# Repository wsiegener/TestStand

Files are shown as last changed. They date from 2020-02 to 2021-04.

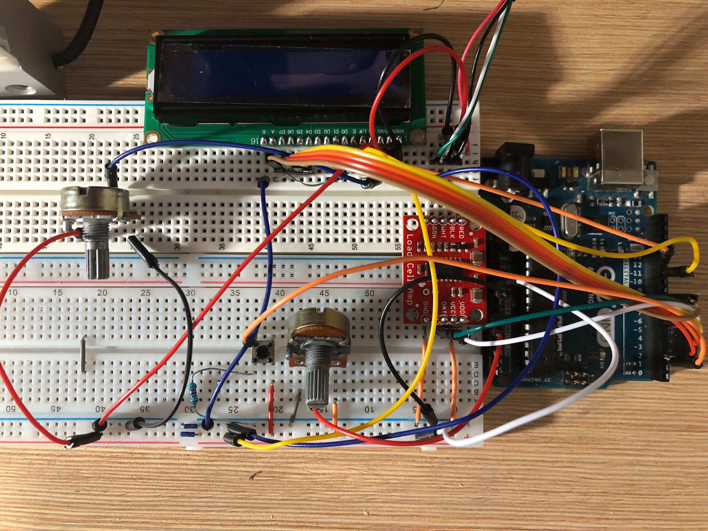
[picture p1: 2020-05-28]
Documentation/Breadboard_pic2_2_26.jpg

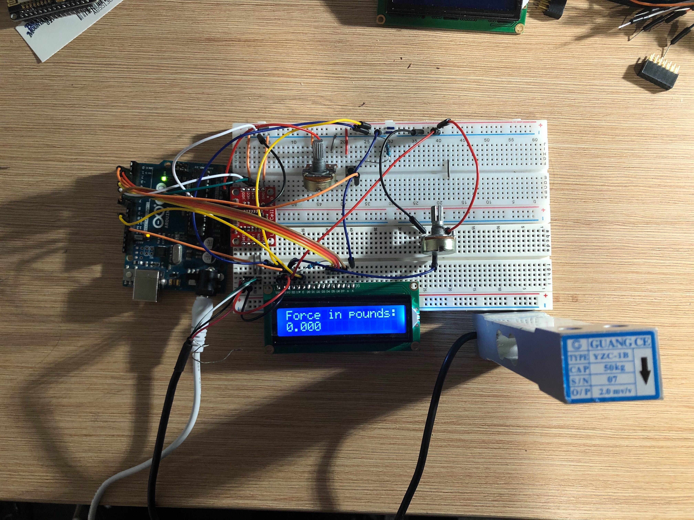
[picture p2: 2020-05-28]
Documentation/Breadboard_pic1_2_26.jpg

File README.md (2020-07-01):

# Model Rocket Thrust Measurement Test Stand
* An RIT SPEX solo project developed by Billy Siegener

### Current Functionality
* Records and displays measurements from a 50kg load cell via an [HX711](https://cdn.sparkfun.com/datasheets/Sensors/ForceFlex/hx711_english.pdf "Amplifier datasheet") load cell amplifier module.
  * [HX711 Library](https://github.com/bogde/HX711 "HX711Library")
* Automatic scale factor tuning
* Improved tare functionality for dealing with noisy circuitry
* 1602A LCD implemenation

### Future Functionality
* ...

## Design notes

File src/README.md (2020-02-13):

# Model Rocket Thrust Measurement Test Stand
* An RIT SPEX solo project developed by Billy Siegener

### Current Functionality
* Records and displays measurements from a 50kg load cell via an [HX711](https://cdn.sparkfun.com/datasheets/Sensors/ForceFlex/hx711_english.pdf "Amplifier datasheet") load cell amplifier module.
  * [HX711 Library](https://github.com/bogde/HX711 "HX711Library")
* Scale factor tuning via potentiometer
* Improved tare functionality for dealing with noisy circuitry

### Future Functionality
* Wireless data transmission via [NRF24L01+](https://www.sparkfun.com/datasheets/Components/nRF24L01_prelim_prod_spec_1_2.pdf "Datasheet") modules.
  * [NRF24L01 Library](https://github.com/nRF24/RF24)
* 1602A LCD implemenation
* ...

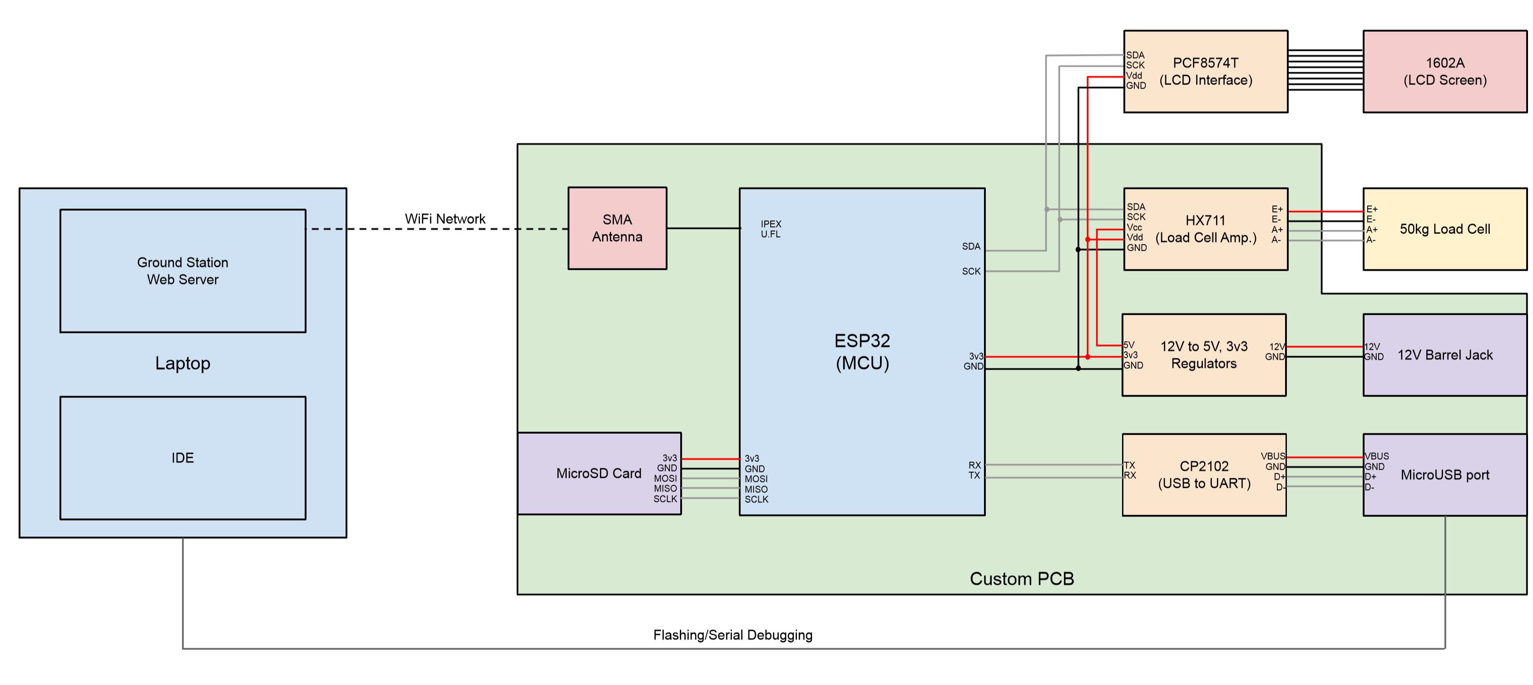
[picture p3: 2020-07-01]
Documentation/BlockDiagram_v1c.JPG

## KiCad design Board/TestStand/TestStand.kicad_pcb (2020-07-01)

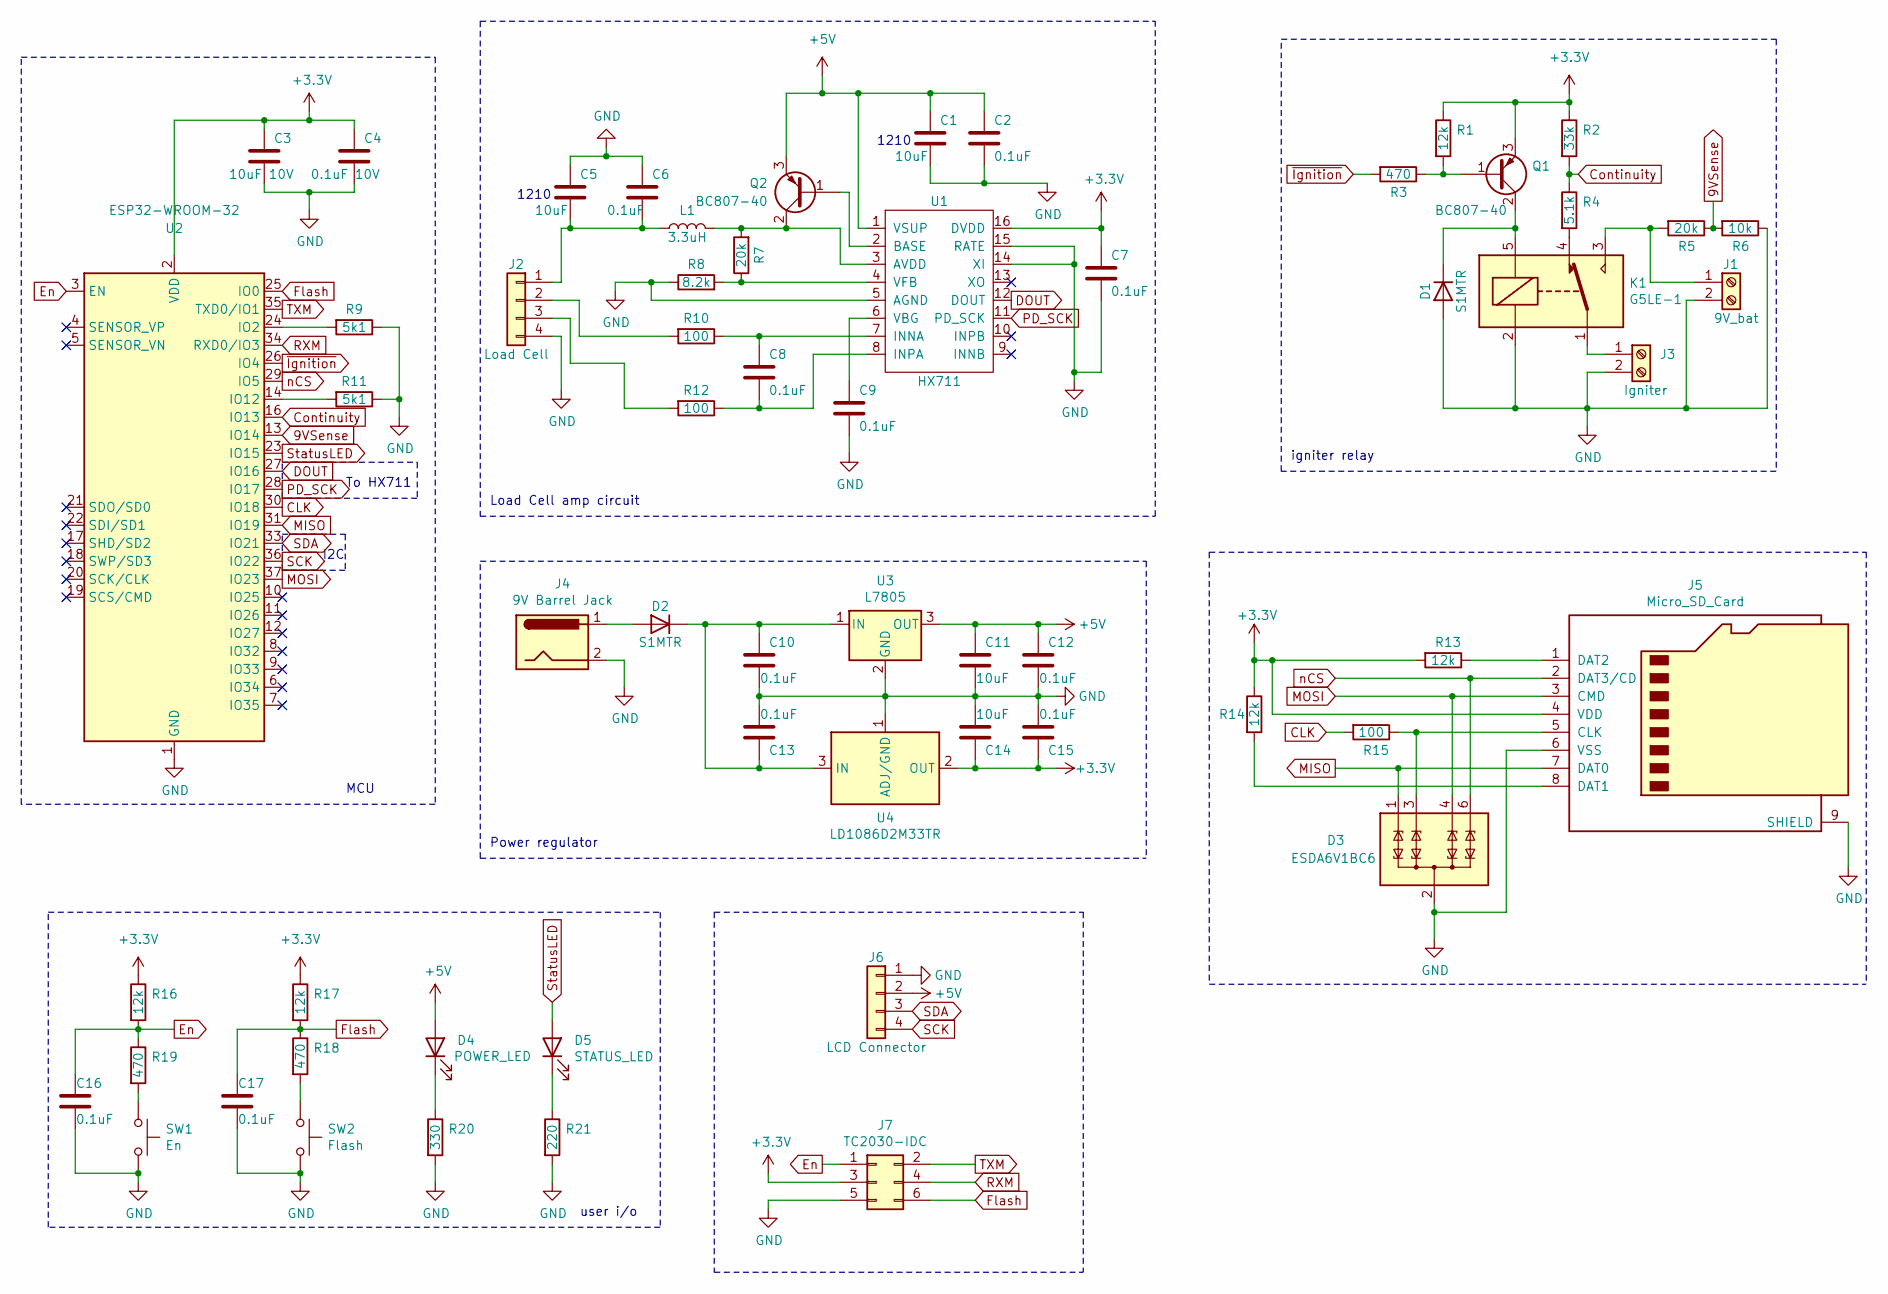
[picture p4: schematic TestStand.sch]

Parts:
C1, C5: 10uF; C_1210_3225Metric_Pad1.42x2.65mm_HandSolder
C2, C6, C7, C8, C9, C10, C12, C13, C15, C16, C17: 0.1uF; C_0805_2012Metric_Pad1.15x1.40mm_HandSolder
C3: 10uF 10V; C_0805_2012Metric_Pad1.15x1.40mm_HandSolder
C4: 0.1uF 10V; C_0805_2012Metric_Pad1.15x1.40mm_HandSolder
C11, C14: 10uF; C_0805_2012Metric_Pad1.15x1.40mm_HandSolder
D1, D2: S1MTR; D_SMA_Handsoldering
D3: ESDA6V1BC6; SOT-23-6
D4: POWER_LED; LED_Rectangular_W5.0mm_H2.0mm
D5: STATUS_LED; LED_Rectangular_W5.0mm_H2.0mm
J1: 9V_bat; TerminalBlock_Phoenix_PT-1,5-2-5.0-H_1x02_P5.00mm_Horizontal
J2: Load Cell; Molex_Micro-Fit_3.0_43045-0400_2x02_P3.00mm_Horizontal
J3: Igniter; TerminalBlock_Phoenix_PT-1,5-2-5.0-H_1x02_P5.00mm_Horizontal
J4: 9V Barrel Jack; BarrelJack_CUI_PJ-036AH-SMT_Horizontal
J5: Micro_SD_Card; microSD_HC_Molex_104031-0811
J6: LCD Connector; PinHeader_1x04_P2.54mm_Vertical
J7: TC2030-IDC; Tag-Connect_TC2030-IDC-FP_2x03_P1.27mm_Vertical
K1: G5LE-1; Relay_SPDT_Omron-G5LE-1
L1: 3.3uH; L_0805_2012Metric_Pad1.15x1.40mm_HandSolder
Q1, Q2: BC807-40; SOT-23_Handsoldering
R1, R13, R14, R16, R17: 12k; R_0805_2012Metric_Pad1.15x1.40mm_HandSolder
R2: 33k; R_0805_2012Metric_Pad1.15x1.40mm_HandSolder
R3, R18, R19: 470; R_0805_2012Metric_Pad1.15x1.40mm_HandSolder
R4: 5.1k; R_0805_2012Metric_Pad1.15x1.40mm_HandSolder
R5, R7: 20k; R_0805_2012Metric_Pad1.15x1.40mm_HandSolder
R6: 10k; R_0805_2012Metric_Pad1.15x1.40mm_HandSolder
R8: 8.2k; R_0805_2012Metric_Pad1.15x1.40mm_HandSolder
R9, R11: 5k1; R_0805_2012Metric_Pad1.15x1.40mm_HandSolder
R10, R12, R15: 100; R_0805_2012Metric_Pad1.15x1.40mm_HandSolder
R20: 330; R_0805_2012Metric_Pad1.15x1.40mm_HandSolder
R21: 220; R_0805_2012Metric_Pad1.15x1.40mm_HandSolder
SW1: En; SW_Push_1P1T_NO_6x6mm_H9.5mm
SW2: Flash; SW_Push_1P1T_NO_6x6mm_H9.5mm
U1: HX711; STC_SOP-16_3.9x9.9mm_P1.27mm
U2: ESP32-WROOM-32; ESP32-WROOM-32U
U3: L7805; TO-263-2
U4: LD1086D2M33TR; TO-263-3_TabPin2

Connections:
9VSense: R5.1, R6.2, U2.13 (IO14)
+3V3: C3.1, C4.1, C7.1, C14.2, C15.2, J5.4 (VDD), J7.3, Q1.3 (E), R1.1, R2.1, R13.2, R14.1, R16.1, R17.1, U1.16 (DVDD), U2.2 (VDD), U4.2 (OUT)
+5V: C1.1, C2.1, C11.1, C12.1, D4.2 (A), J6.2, Q2.3 (E), U1.1 (VSUP), U3.3 (OUT)
CLK: R15.2, U2.30 (IO18)
Continuity: R2.2, R4.1, U2.16 (IO13)
DOUT: U1.12 (DOUT), U2.27 (IO16)
En: C16.1, J7.1, R16.2, R19.1, U2.3 (EN)
Flash: C17.1, J7.6, R17.2, R18.1, U2.25 (IO0)
GND: C1.2, C2.2, C3.2, C4.2, C5.1, C6.1, C7.2, C9.2, C10.2, C11.2, C12.2, C13.1, C14.1, C15.1, C16.2, C17.2, D1.2 (A), D3.2 (COM), D3.5 (COM), J1.2, J2.4, J3.2, J4.2, J5.6 (VSS), J5.9 (SHIELD), J6.1, J7.5, K1.2, R6.1, R8.1, R9.1, R11.1, R20.2, R21.2, SW1.2, SW2.2, U1.5 (AGND), U1.14 (XI), U1.15 (RATE), U2.1 (GND), U2.15 (GND), U2.38 (GND), U2.39 (GND), U3.2 (GND), U4.1 (ADJ/GND)
Ignition: R3.2, U2.26 (IO4)
MISO: D3.1 (TVS1), J5.7 (DAT0), U2.31 (IO19)
MOSI: D3.4 (TVS3), J5.3 (CMD), U2.37 (IO23)
unnamed: C5.2, C6.2, J2.1, L1.1
unnamed: C8.1, R10.1, U1.7 (INNA)
unnamed: C8.2, R12.1, U1.8 (INPA)
unnamed: C9.1, U1.6 (VBG)
unnamed: C10.1, C13.2, D2.1 (K), U3.1 (IN), U4.3 (IN)
unnamed: D1.1 (K), K1.5, Q1.2 (C)
unnamed: D2.2 (A), J4.1
unnamed: D3.3 (TVS2), J5.5 (CLK), R15.1
unnamed: D4.1 (K), R20.1
unnamed: D5.1 (K), R21.1
unnamed: J1.1, K1.3, R5.2
unnamed: J2.2, R10.2
unnamed: J2.3, R12.2
unnamed: J3.1, K1.1
unnamed: J5.1 (DAT2), R13.1
unnamed: J5.8 (DAT1), R14.2
unnamed: K1.4, R4.2
unnamed: L1.2, Q2.2 (C), R7.2, U1.3 (AVDD)
unnamed: Q1.1 (B), R1.2, R3.1
unnamed: Q2.1 (B), U1.2 (BASE)
unnamed: R7.1, R8.2, U1.4 (VFB)
unnamed: R9.2, U2.24 (IO2)
unnamed: R11.2, U2.14 (IO12)
unnamed: R18.2, SW2.1
unnamed: R19.2, SW1.1
PD_SCK: U1.11 (PD_SCK), U2.28 (IO17)
RXM: J7.4, U2.34 (RXD0/IO3)
SCK: J6.4, U2.36 (IO22)
SDA: J6.3, U2.33 (IO21)
StatusLED: D5.2 (A), U2.23 (IO15)
TXM: J7.2, U2.35 (TXD0/IO1)
nCS: D3.6 (TVS4), J5.2 (DAT3/CD), U2.29 (IO5)

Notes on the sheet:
I2C
1210
Load Cell amp circuit
Power regulator
user i/o
MCU
To HX711
igniter relay

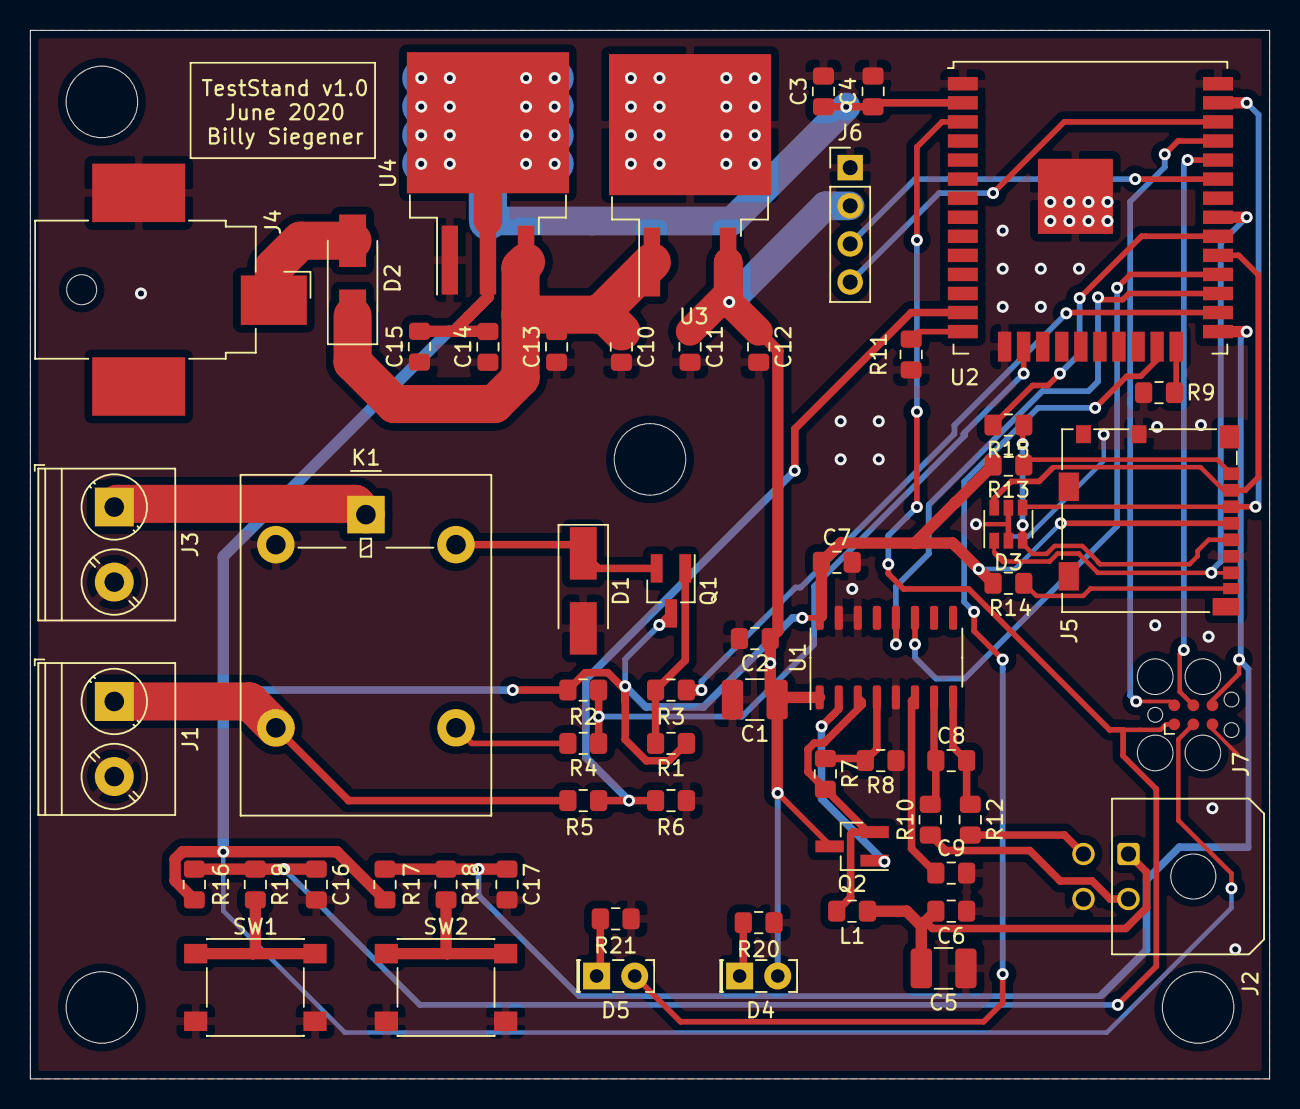
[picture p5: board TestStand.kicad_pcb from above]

Board: 2 copper layers, 82.5 x 69.9 mm, 60 parts (0 on the bottom side), 44 nets.

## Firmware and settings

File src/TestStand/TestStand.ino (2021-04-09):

/**
 * 
 */

#include <Wire.h>
#include <LiquidCrystal_I2C.h>
#include "HX711.h"

#include <Arduino.h>
#include <WiFi.h>
#include <WiFiClientSecure.h>
#include <WebSocketsServer.h>

WebSocketsServer webSocket = WebSocketsServer(80);

bool conn_ = false;

void webSocketEvent(uint8_t num, WStype_t type, uint8_t * payload, size_t length) 
{
    switch(type) 
    {
        case WStype_DISCONNECTED:
            Serial.printf("[%u] Disconnected!\n", num);
            break;
        case WStype_CONNECTED:
            {
                IPAddress ip = webSocket.remoteIP(num);
                Serial.printf("[%u] Connected from %d.%d.%d.%d url: %s\n", num, ip[0], ip[1], ip[2], ip[3], payload);

                webSocket.sendTXT(num, "Connected");

                conn_ = true;
            }
            break;
        case WStype_TEXT:
            Serial.printf("[%u] get Text: %s\n", num, payload);

            // send message to client
            webSocket.sendTXT(num, "message here");

            // send data to all connected clients
            // webSocket.broadcastTXT("message here");
            break;
        case WStype_BIN:
        case WStype_ERROR:      
        case WStype_FRAGMENT_TEXT_START:
        case WStype_FRAGMENT_BIN_START:
        case WStype_FRAGMENT:
        case WStype_FRAGMENT_FIN:
      break;
    }
}

HX711 loadcell;
//LiquidCrystal_I2C lcd(0x27,16,2);  // set the LCD address to 0x27 for a 16 chars and 2 line display

const int POT_PIN = 4;
const int TARE_PIN= 0;
const int LOADCELL_DOUT_PIN = 16;
const int LOADCELL_SCK_PIN= 17;

const int ZERO_POINT= 200;

/**
 * STATES:
 *  0 - update values as normal
 *  1 - tare mode
 *  2 - update, record, and transmit values 
 *  3 - idle?
 */
int STATE = 0;

int TARE_DONE = 0;

double scale_val = 79.28;
int last_pot = 0;

void setup()
{
    Serial.begin(115200);

    pinMode(12, OUTPUT);
    pinMode(14, OUTPUT);

    digitalWrite(12, LOW);
    
    //lcd.init();                      // initialize the lcd 
    //lcd.backlight();

    WiFi.begin("NETWORK", "PASSWORD");

    while (WiFi.status() != WL_CONNECTED) 
    {
        delay(500);
        Serial.print(".");
    }

    Serial.println("Connected!");
    digitalWrite(12, HIGH);


    webSocket.begin();
    webSocket.onEvent(webSocketEvent);

    loadcell.begin(LOADCELL_DOUT_PIN, LOADCELL_SCK_PIN);

    Serial.println("After load cell begin");

    Serial.println("Taring Scale");

    update_reading();
    
    loadcell.set_scale(scale_val);

    Serial.println("Scale is set");

    loadcell.tare();
    
    Serial.println("Tared");

    tare_scale();
    
    attachInterrupt(digitalPinToInterrupt(TARE_PIN), toggleMode, RISING);   

}


bool status_ = false;

void loop() 
{
    if(!status_)
    {
        if(conn_)
        {
            digitalWrite(14, HIGH);
            status_ = true;
        }
    }
    webSocket.loop();
    switch(STATE)
    {
      case 0:
      {
        if(TARE_DONE == 0) // state needs to be changed
        {
          STATE = 1;
        }
        else
        {
          update_reading();
        }
        break;
      }
      case 1:
      {
        if(TARE_DONE == 0) // if call for tare
        {
          tare_scale();
        }
        else if(TARE_DONE == 2)
        {
          // TARE RUNNING
        }
        else if(TARE_DONE == 1)
        {
          STATE = 0;
        }
        break;
      }
      default:
      {
        break;
      }
    }

    delay(5);
}

float value = 0;
float t_ = 0;
String msg = "";

void update_reading()
{


  
    //lcd.setCursor(0,0);
    //lcd.print("Force in kgs:"); 

    //scale_val = map(analogRead(POT_PIN), 0, 4095, 79000, 81000) / 1000.0;

    if (loadcell.wait_ready_timeout(1000)) 
    {
        long reading = loadcell.get_units(1);
        //Serial.print("HX711 reading with value of ");
        //Serial.print(scale_val);
        //Serial.print("\t");

        t_ = millis();
        value = reading;
        
        msg = String(t_) + ": " + String(value);
        webSocket.broadcastTXT(msg);

        
        Serial.println((double) reading / 1.0);
        

        //lcd.setCursor(0,1);
        //lcd.print(reading / 1000.0);
    }
    else 
    {
        Serial.println("HX711 not found.");
    }
    
    last_pot = analogRead(POT_PIN);
}

void tare_scale()
{
    //Serial.println("Beginning Tare Process");
    
    TARE_DONE = 2;

    int value = 1000;
    int zero_trial = 1;
    int zero_count = 0;
    int last_zero = 1;

    interrupts();

    while(TARE_DONE == 2)
    {
        if(zero_trial > 50)
        {
            //Serial.println("Tare process timeout, zero not found.");
            TARE_DONE = 1;
            break;
        }

        loadcell.set_scale(scale_val);
        loadcell.tare();
        value = loadcell.get_value(5 + zero_trial);

        
        Serial.print("zero_trial: ");
        Serial.print(zero_trial);
        Serial.print("\tRaw: ");
        Serial.print(value);
        Serial.print("\tlbs: ");
        Serial.print((double)value / (1000.0 * scale_val));
        Serial.print("\tZero Count: ");
        Serial.println(zero_count);
        
          
         

        // if value is in zero range
        if(abs(value) < ZERO_POINT)
        {
            // if last check was a valid zero, increment
            if(last_zero)
            {
                zero_count++;
                //Serial.print("Zero count is now: ");
                //Serial.println(zero_count);
            }
            else // else this is the first zero in sequence
            {
                zero_count = 1;
                //Serial.println("First Zero!");
            }
            last_zero = 1;
        }
        else if(last_zero) // reset if no zero is found immediately after
        {
            last_zero = 0;
            zero_count = 0;
        }

        if(zero_count >= 3)
        {
            //Serial.println("Taring successful!");
            TARE_DONE = 1;
            break;
        }

        // incrememnt timeout count
        zero_trial++;
        delay(10);
    }

    //Serial.println("");
}

void toggleMode()
{  
    // disable interrupts for debounce
    noInterrupts();

    delay(20);

    if(digitalRead(TARE_PIN))
    {        
        if(STATE == 1) // if we are in tare mode, we want to cancel that
        {
            Serial.println("Cancelling Tare Mode.");
            TARE_DONE = 1;
            
            interrupts();
        }
        else if(STATE == 0)
        {
            Serial.println("Setting to Tare Mode.");            
            TARE_DONE = 0;
        }
    }    
}


// end file

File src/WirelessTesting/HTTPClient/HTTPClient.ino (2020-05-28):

/**
 * HTTPClient 
 * 
 */

#include "WiFi.h"

const char* ssid = "FiOS-3I4B5";
const char* pass = "bip8cycle8316pup";

String server = "PLACEHOLDER";

void setup() 
{
  Serial.begin(115200);

  WiFi.begin(ssid, pass);
  Serial.println("Connecting");
  
  while(WiFi.status() != WL_CONNECTED)
  {
    delay(500);
    Serial.print(".");
  }
  Serial.println("");
  Serial.print("Connected to Network with IP: ");
  Serial.println(WiFi.localIP());
}

void loop() 
{

}

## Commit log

2020-05-28 - refactor file heirarchy - add wireless testing code
2020-07-01 - add kicad board schematic and pcb design - add state machine logic
    [TestStand.kicad_pcb, TestStand.sch]
